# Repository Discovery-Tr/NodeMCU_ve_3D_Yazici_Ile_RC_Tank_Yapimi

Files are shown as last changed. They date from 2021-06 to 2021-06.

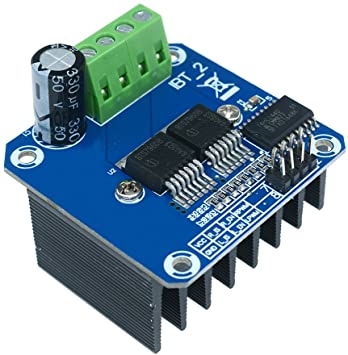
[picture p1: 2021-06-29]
BTS7960B.jpg

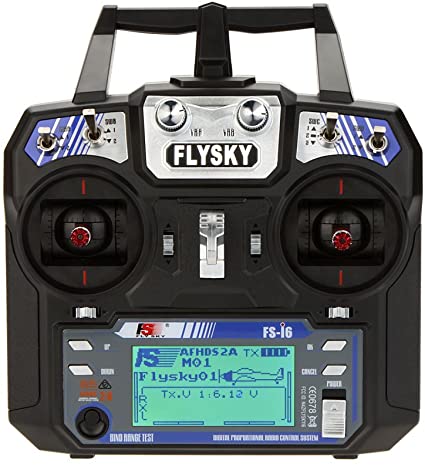
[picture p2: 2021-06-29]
flysky.jpg

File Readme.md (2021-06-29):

# EVDE 3D YAZICI İLE TANK YAPMAK ( RC + NODEMCU )

<p align="center">
  <a href="https://www.youtube.com/watch?v=Ha2aAsPUa1s" target="_blank">
  
 </a>
</p>

      Merhaba, bu yazımızda evde Rc tank yapımı ve programlamasına değineceğiz. Bütün parça devre şeması ve yazılımını sizlerle paylaşacağım.

      Rc yi radyo kontrolü olarak Türkçeye çevirebiliriz. RC (Radio Control ), bir cihazı radyo frekansı ile uzaktan kontrol etmek için kullanılır. TV’lerimizde kullandığımız uzaktan kumanda ile de kontrol edebiliriz fakat mesafe hem uzak olmaz. Hem de kumanda ve cihaz sürekli birbirini görmek zorunda kalır.  Özellikle hobi devrelerinde sıkça tercih kullanılırlar. RC tank, RC araç, RC tekne ve RC drone örnek olarak gösterile bilir. 

      Bu projemizde tankımız yaklaşık 25Km hız ve 2-3 Km (Açık alanda) kapsama alanı içerisinde kontrol edebiliriz.  Kamera bağlantısı yapılarak tankımızı görmesek te görüntü ile yönlendirmemiz mümkündür.

      Bir oyuncaktan çok bir keşif robotu yada üzerine bağlanacak değişik eklentiler sayesinde istenilen özellikler eklenebilir.

# 3D Çizim Aşamaları
<p align="center">
  
  
  
  
</p>

# Devre Şeması
<p align="center">
  
</p>

   Projede kullanılan 2 servo motor Turret kontrolü içindir. Biri namlu yukarı aşağı diğeri ise namlunun sağa sola dönüşü içindir.

# Proje Yazılımı
```
/* Receiver 2 ve 4*/
#define Ch_Sag_Motor 14 //D5
#define Ch_Sol_Motor 12 //D6
int ch2=0;
int ch4=0;

//Sol Motor
#define Sol_LPWM  16 //lpwm D0
#define Sol_RPWM  5 //rpwm D1
#define Sol_PWM   4 //pwm enable D7

//Sag Motor
#define Sag_LPWM  0 //lpwm D3
#define Sag_RPWM  2 //rpwm D4
#define Sag_PWM   13 //pwm enable D2

void setup()
{
  pinMode(Sol_LPWM, OUTPUT);
  pinMode(Sol_RPWM, OUTPUT);
  pinMode(Sol_PWM, OUTPUT);

  pinMode(Sag_LPWM, OUTPUT);
  pinMode(Sag_RPWM, OUTPUT);
  pinMode(Sag_PWM, OUTPUT);
  
  pinMode(Ch_Sag_Motor,INPUT);
  pinMode(Ch_Sol_Motor,INPUT);
  Serial.begin(9600); //9600 Baund bir seri haberleşme başlatıyoruz
}

void loop()
{
  ch2= pulseIn(Ch_Sag_Motor,HIGH,50000);
  ch4= pulseIn(Ch_Sol_Motor,HIGH,50000);

  switch(ch4)
        {
            case 1858 ... 2100: 
            Serial.print("Sol Motor - İleri - Hızlı: ");
            Serial.println(ch4);
            analogWrite(Sol_PWM, 650);
            Sol_Motor_Ileri ();
            break;
            
            case 1730 ... 1857: 
            Serial.print("Sol Motor - İleri - Orta: ");
            Serial.println(ch4);  
            analogWrite(Sol_PWM, 500);
            Sol_Motor_Ileri ();

            break;
            
            case 1601 ... 1729: 
            Serial.print("Sol Motor - İleri - Yavas: ");
            Serial.println(ch4); 
            analogWrite(Sol_PWM, 400);
            Sol_Motor_Ileri ();

            break;
            
            case 1391 ... 1600: 
            Serial.print(""); 
            analogWrite(Sol_PWM, 0);
            Sol_Motor_Dur ();

            break;
            
            case 1266 ... 1390: 
            Serial.print("Sol Motor - Geri - Yavas: ");
            Serial.println(ch4); 
            analogWrite(Sol_PWM, 400); //0-255
            Sol_Motor_Geri();

            break;
            
            case 1143 ... 1265: 
            Serial.print("Sol Motor - Geri - Orta: ");
            Serial.println(ch4);  
            analogWrite(Sol_PWM, 500); //0-255
            Sol_Motor_Geri();

            break;
            
            case 900 ... 1142:  
            Serial.print("Sol Motor - Geri - Hızlı: ");
            Serial.println(ch4); 
            analogWrite(Sol_PWM, 650); //0-255
            Sol_Motor_Geri();

            break;
            
            default: printf("");break;
        }

switch(ch2)
        {
            case 1858 ... 2100: 
            Serial.print("\t\t\t\t\t"); 
            Serial.print("Sag Motor - İleri - Hızlı: ");
            Serial.println(ch2);  
            analogWrite(Sag_PWM, 650);
            Sag_Motor_Ileri ();
            break;
            
            case 1730 ... 1857: 
            Serial.print("\t\t\t\t\t"); 
            Serial.print("Sag Motor - İleri - Orta: ");
            Serial.println(ch2);  
            analogWrite(Sag_PWM, 500);
            Sag_Motor_Ileri ();
            break;
            
            case 1601 ... 1729: 
            Serial.print("\t\t\t\t\t"); 
            Serial.print("Sag Motor - İleri - Yavas: ");
            Serial.println(ch2); 
            analogWrite(Sag_PWM, 400);
            Sag_Motor_Ileri ();
            break;
            
            case 1391 ... 1600: 
            Serial.print(""); 
            analogWrite(Sag_PWM, 0);
            Sag_Motor_Dur ();
            break;
            
            case 1266 ... 1390: 
            Serial.print("\t\t\t\t\t"); 
            Serial.print("Sag Motor - Geri - Yavas: ");
            Serial.println(ch2);
            analogWrite(Sag_PWM, 400); //0-255
            Sag_Motor_Geri(); 
            break;
            
            case 1143 ... 1265: 
            Serial.print("\t\t\t\t\t"); 
            Serial.print("Sag Motor - Geri - Orta: ");
            Serial.println(ch2);
            analogWrite(Sag_PWM, 500); //0-255
            Sag_Motor_Geri(); 
            break;
            
            case 900 ... 1142:  
            Serial.print("\t\t\t\t\t"); 
            Serial.print("Sag Motor - Geri - Hızlı: ");
            Serial.println(ch2);  
            analogWrite(Sag_PWM, 650); //0-255
            Sag_Motor_Geri();
            break;
            
            default: printf("");break;
        }  
}

void  Sol_Motor_Ileri ()
{
digitalWrite(Sol_LPWM, HIGH);
digitalWrite(Sol_RPWM, LOW);
}

void Sol_Motor_Dur ()
{
  digitalWrite(Sol_LPWM, LOW);
  digitalWrite(Sol_RPWM, LOW);
}
void Sol_Motor_Geri()
{
digitalWrite(Sol_LPWM, LOW);
digitalWrite(Sol_RPWM, HIGH);
}

///
void  Sag_Motor_Ileri ()
{
digitalWrite(Sag_LPWM, HIGH);
digitalWrite(Sag_RPWM, LOW);
}

void Sag_Motor_Dur ()
{
  digitalWrite(Sag_LPWM, LOW);
  digitalWrite(Sag_RPWM, LOW);
}
void Sag_Motor_Geri()
{
digitalWrite(Sag_LPWM, LOW);
digitalWrite(Sag_RPWM, HIGH);
}
 ```

# MALZEMELER
# Kumanda:
Flysky i6 X1
<p align="center">
  
</p>

Kumanda Ayarlaması için <a href="https://www.kirmiziyuz.com/arduino/arduino-ile-rc-kumanda-kullanimi.html
">tıklayınız.</a>

# Reciever:
FlySky FS-iA6 Receiver 6CH 2.4G
<p align="center">
  
</p>

# Motorlar:
55T Motor x2
<p align="center">
  
</p>

Servo Motor x2

# Motor Sürücü:
20 Amper Motor Sürücü Kartı BTS7960B  x2
<p align="center">
  
</p>

# Rulman:

8x22x7mm 608 12x

4x13x5mm 624 12x

# Vidalar:

M4x15mm 8x

M4x60mm 12x

M3x20mm 4x

M3x10mm 4x

M3x45mm 84x

# Somun:

M4 20x

M3 88x

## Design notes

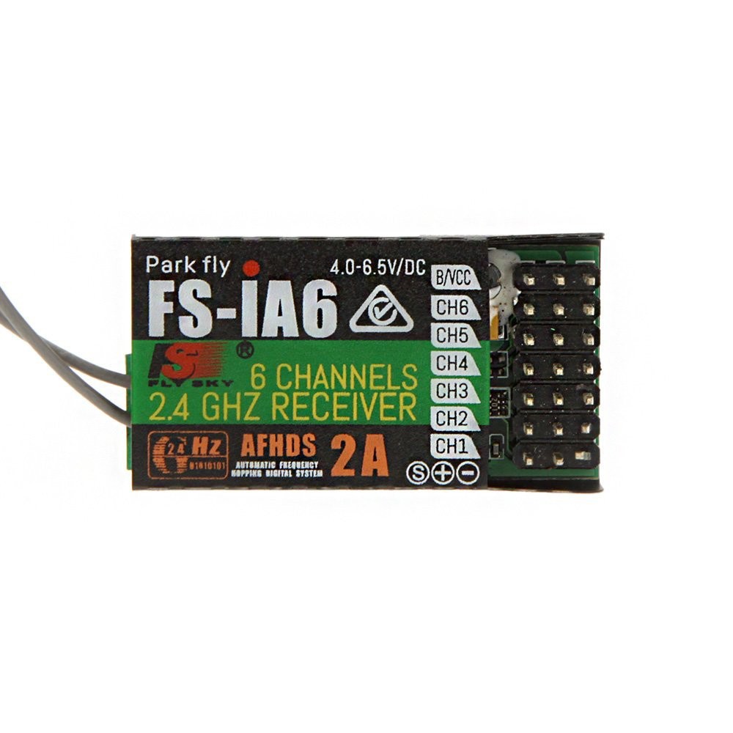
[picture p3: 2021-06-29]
flysky-fs-ia6-receiver-lead.jpg

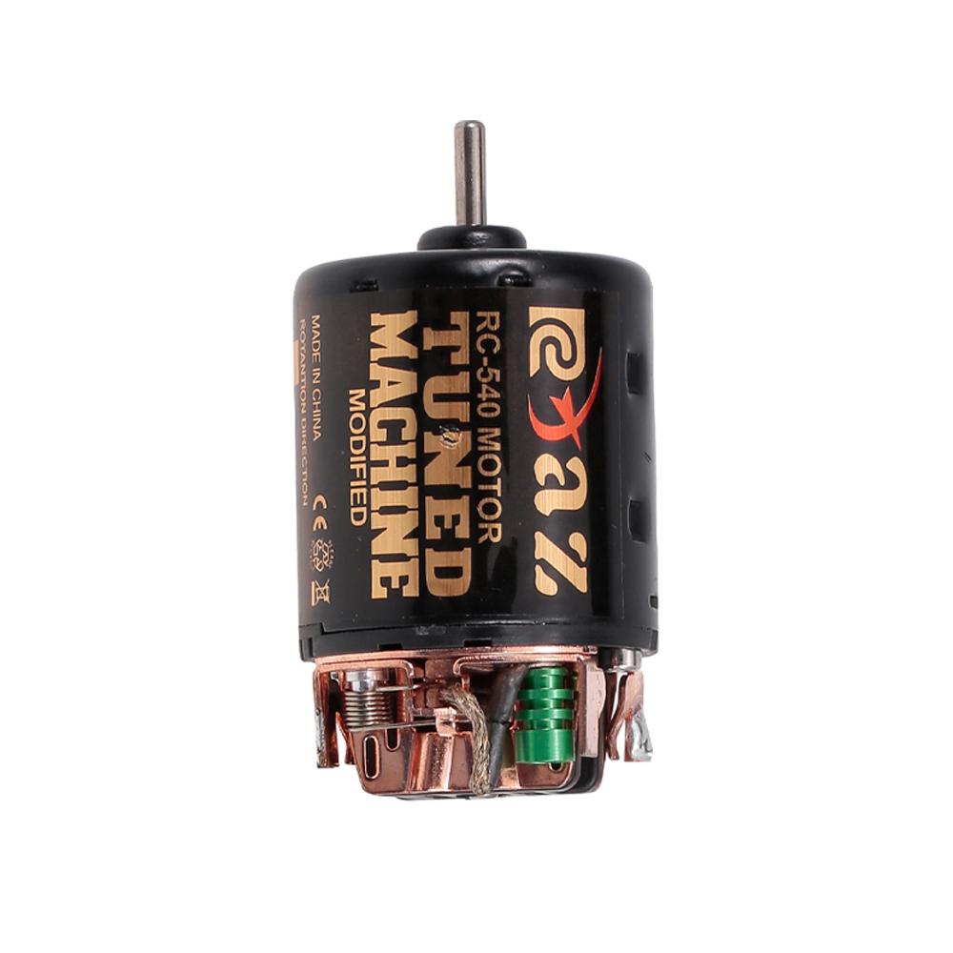
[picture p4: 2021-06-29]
55T Motor.jpeg

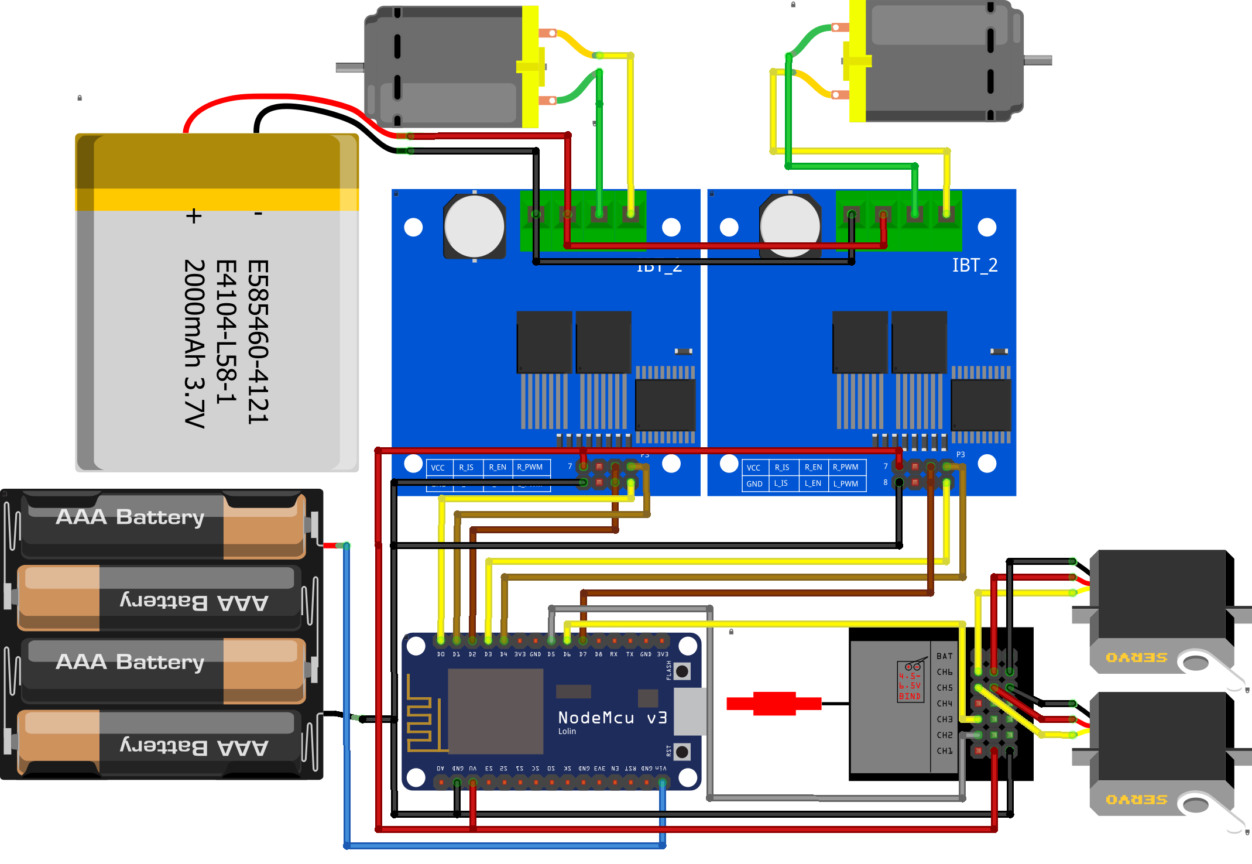
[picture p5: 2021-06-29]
NodeMCU_ve_3D_Yazici_Ile_RC_Tank_Yapimi_Devre_Semasi.png

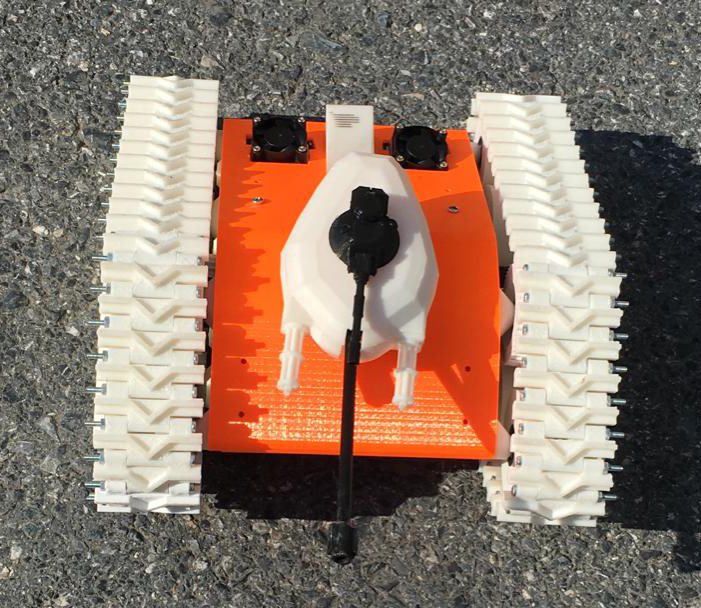
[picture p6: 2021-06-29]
Foto/Rc Speed Tank (2).jpeg

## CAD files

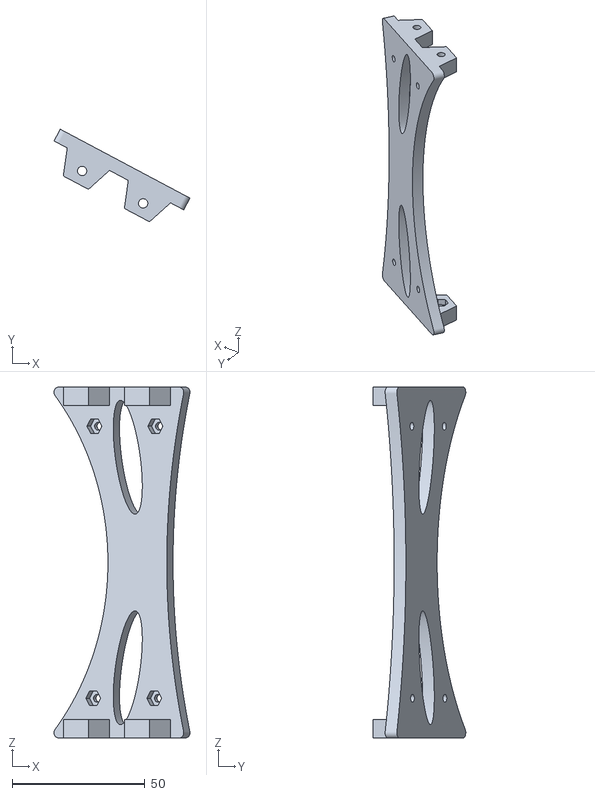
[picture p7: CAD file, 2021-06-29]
3d/Gövde/atkı.stl
51.1 x 34.8 x 132.0

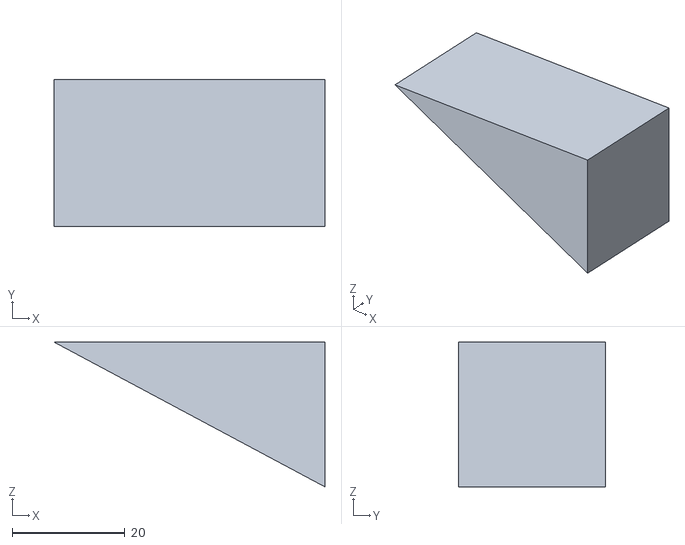
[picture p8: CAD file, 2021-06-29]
3d/Kapak/Tank-Kapak_fanli-pil.stl
48.1 x 26.0 x 25.7

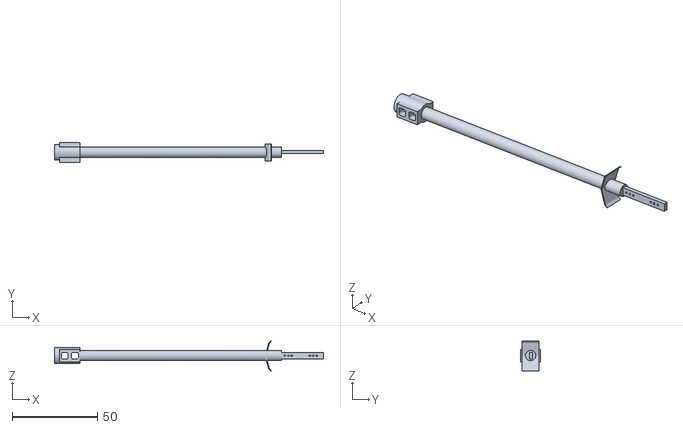
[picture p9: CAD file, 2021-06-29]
3d/Turret/turret-namlu.stl
157.6 x 12.0 x 17.6

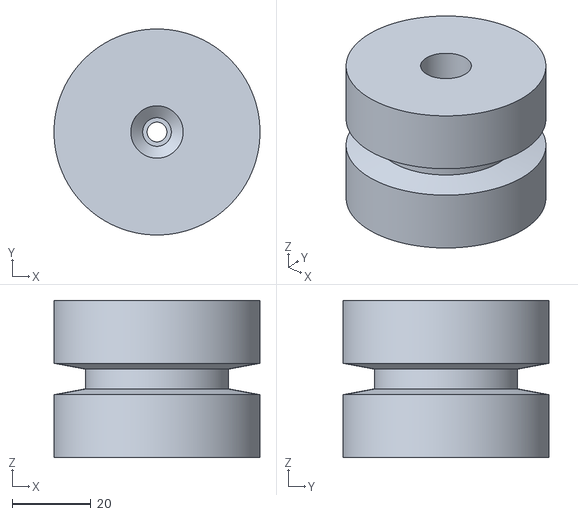
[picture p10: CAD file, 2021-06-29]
3d/Gövde/Taban Tekerleri.stl
52.4 x 52.4 x 40.0

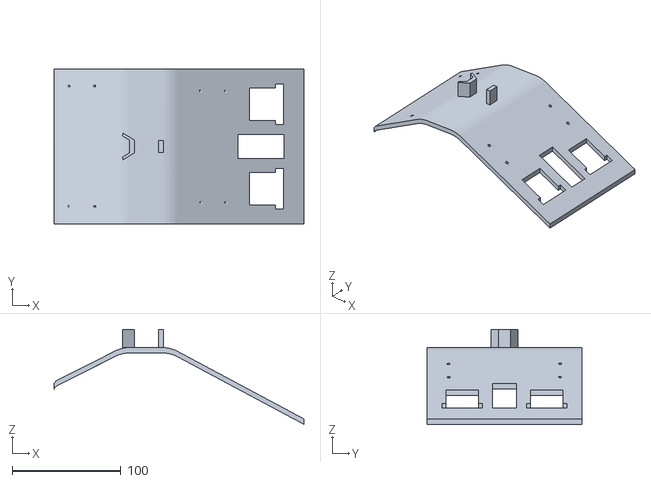
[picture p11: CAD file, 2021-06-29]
3d/Kapak/Tank-Kapak_fanli.stl
229.5 x 142.0 x 87.2

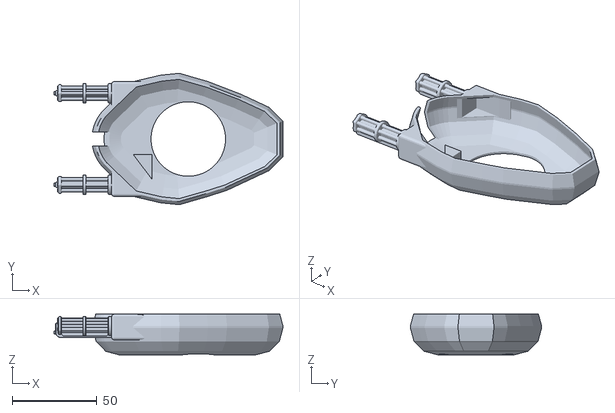
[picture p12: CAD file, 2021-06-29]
3d/Turret/turret.stl
135.3 x 77.6 x 24.0

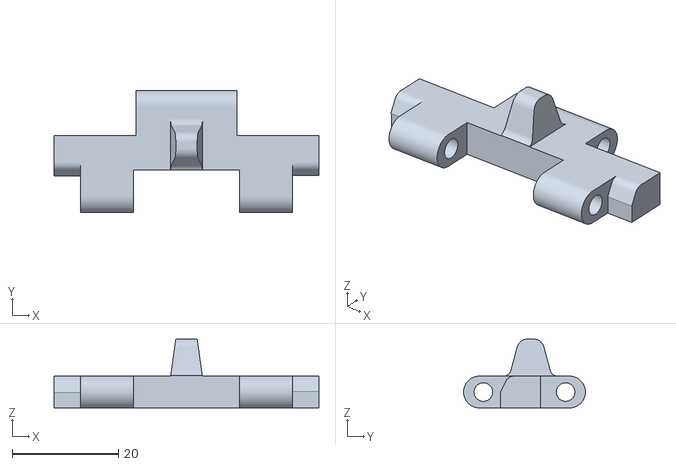
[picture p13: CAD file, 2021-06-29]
3d/Gövde/Tırnaksız Palet.stl
50.0 x 23.0 x 13.0

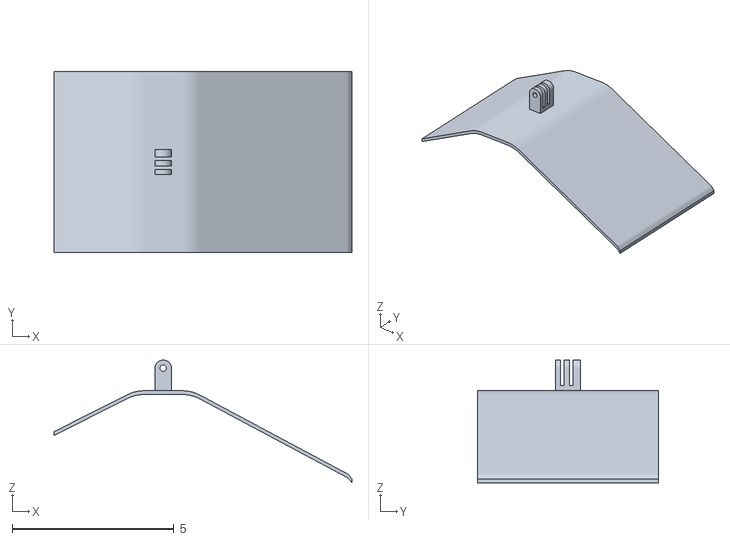
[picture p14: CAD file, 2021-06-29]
3d/Kapak/Kameralı Kapak.stl
9.20 x 5.59 x 3.79

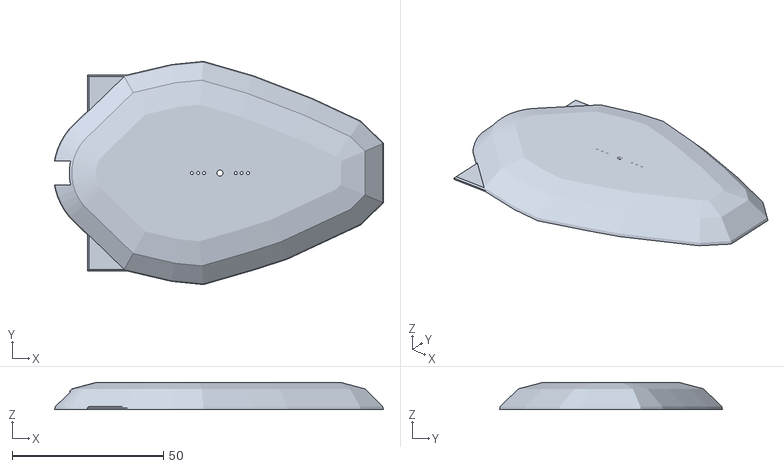
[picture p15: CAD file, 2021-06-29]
3d/Turret/turret-kapak.stl
108.8 x 73.8 x 8.97

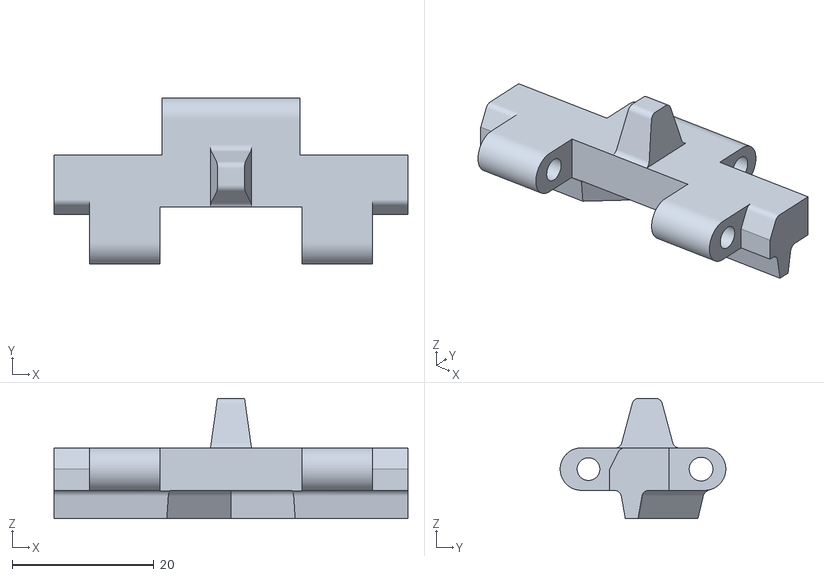
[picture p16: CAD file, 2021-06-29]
3d/Gövde/Tırnaklı Palet.STL
50.0 x 23.4 x 17.0

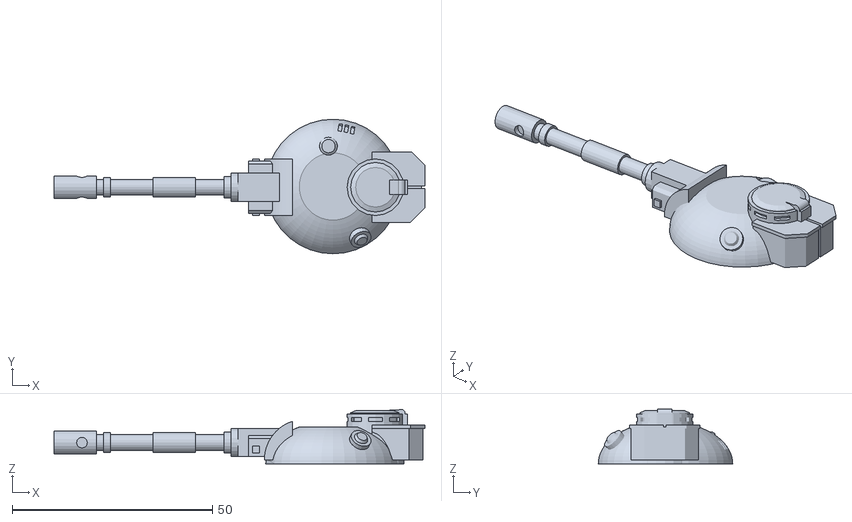
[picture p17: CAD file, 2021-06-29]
3d/Turret/turret-ust-silah.stl
92.7 x 33.6 x 13.6

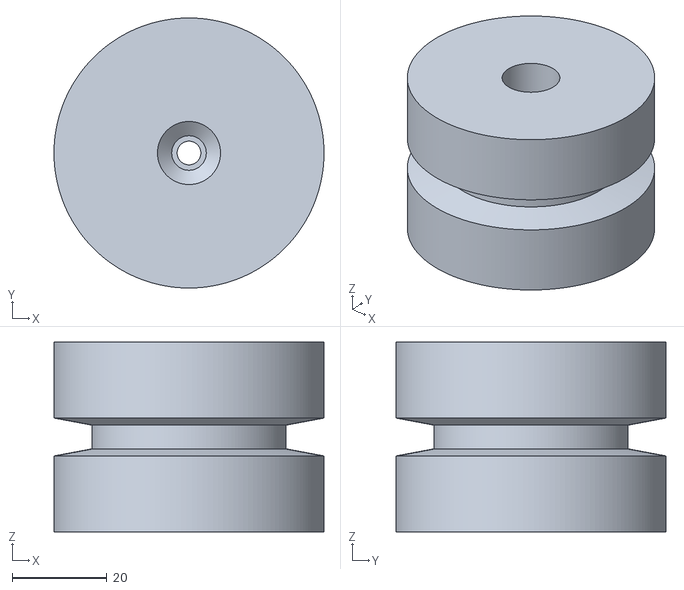
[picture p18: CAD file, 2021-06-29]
3d/Gövde/Burun Gergi Tekeri.stl
57.0 x 57.0 x 40.0

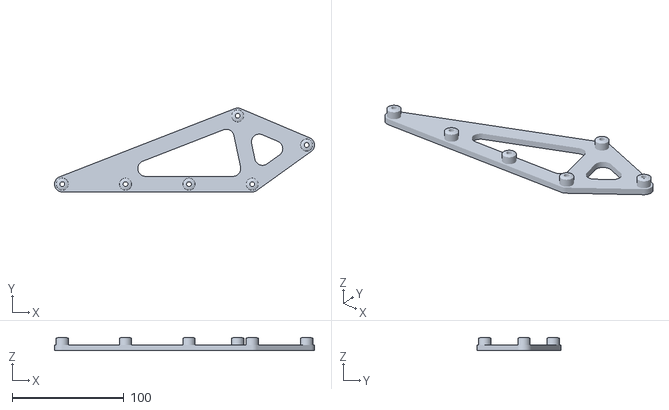
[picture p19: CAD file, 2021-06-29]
3d/Gövde/Sol Teker Kapak.stl
232.7 x 75.1 x 12.0

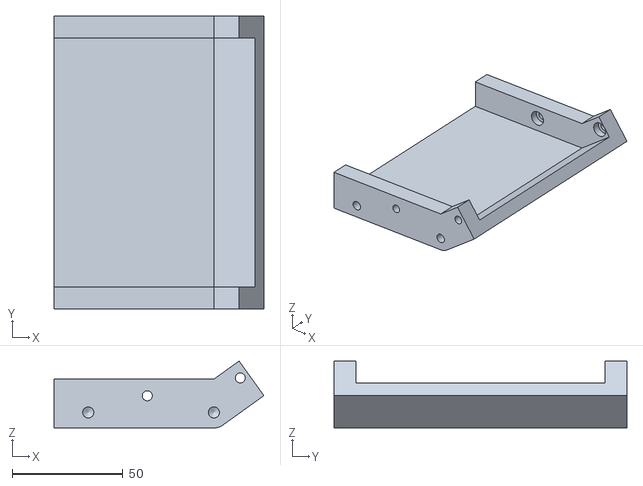
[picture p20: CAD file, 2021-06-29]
3d/Gövde/Taban Ön.stl
94.5 x 132.0 x 30.2

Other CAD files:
3d/Gövde/Sağ Teker Kapak.stl
3d/Gövde/Palet Dişlisi.stl
3d/Gövde/Taban Arka.stl
3d/Gövde/motor_disli.stl
3d/Gövde/burun.stl
